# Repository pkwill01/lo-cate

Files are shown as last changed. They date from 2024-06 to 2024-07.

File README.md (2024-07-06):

# lo-cate
A PCB and firmware project to create a simple LoRa capable device with an intergrated IMU. 
## PCB
The PCB was designed to be simple, power over USB and be manufactorable using basic electrical tooling.

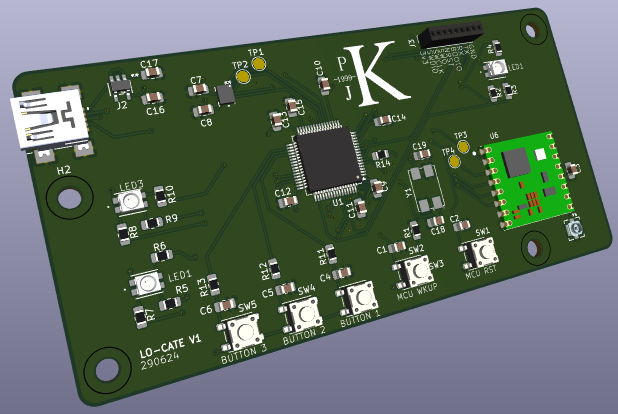
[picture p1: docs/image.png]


### Overview
 - **LoRa**; Connected to the micro via SPI, the antenna connection is terminated to a U.FL SMD connector w/ track impedance matched to 50&Omega;
 - **IMU**; Connected to micro via SPI 
 - **Microcontroller**; STM32F401RET7 w/ an 8MHz external oscillator to allow USB OTG capabilities. 
 - **USB**; Mini B for communicating between the STM and external PC, 5v in fed into a 3.3v linear reg for use by all IC's
 - **LED's**; 3 RGB LED's connected to the micros power outputs for baic HMI
 - **Buttons**; Debounced using RC filter and connected to interrupt capable pins on the micro, MCU WKUP is connected to the micros sleep wakeup pin

### PCB TODO 
 - [] Change the Programming header for the STM32 from the 1.27mm pins
 - [] Fix the oscillator circuit to fit into the STM32 design guidlines C19 & C18 should be calculated via C_L = 2*(C_Load - C_Stray) also R14 will need adjusting also 

## Firmware

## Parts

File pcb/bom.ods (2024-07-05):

Ord | Rec | Component | Spec | $ | Qty | Total $ | Ord | Rec | Reference | Value | Footprint | Qty | $ | Total $
y | y | LoRa Module (https://www.digikey.com.au/en/products/detail/rf-solutions/RFM95W-868S2/5051755?_gl=1*dk7re0*_up*MQ..) | RFM95W-868S2 | 22.68 | 1 | 22.68 | y | y | C1,C2,C3,C4,C5,C6,C7,C8,C9,C10,C11,C12,C13,C14,C16 | 0.1uF (https://www.digikey.com.au/en/products/detail/yageo/CC0805KRX7R9BB104/302874) | C_0805_2012 | 15 | 0.16 | 2.4
y | y | STM32 (https://www.digikey.com.au/en/products/detail/stmicroelectronics/STM32F401RET7/6621729?Enterprise=44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) | STM32F401RET7 | 8.59 | 1 | 8.59 | y | y | C15 | 4.7uF (https://www.digikey.com.au/en/products/detail/samsung-electro-mechanics/CL21A475KAQNNNE/3886902) | C_0805_2013 | 1 | 0.16 | 0.16
y | y | IMU (https://www.digikey.com.au/en/products/detail/bosch-sensortec/BMI323/16719593) | BMI323 | 7.1 | 1 | 7.1 | y | y | C17 | 0.47uF (https://www.digikey.com.au/en/products/detail/murata-electronics/GRM21BR71H474KA88L/702592) | C_0805_2014 | 1 | 0.36 | 0.36
y | y | Buttons (https://www.digikey.com.au/en/products/detail/c-k/PTS-647-SN50-SMTR2-LFS/9649857) | PTS 647 SN50 SMTR2 LFS | 0.28 | 5 | 1.4 | y | y | C18,C19 | 10p (https://www.digikey.com.au/en/products/detail/samsung-electro-mechanics/CL21C100CBANNNC/3888219) | C_0805_2015 | 2 | 0.16 | 0.32
y | y | Led’s (https://www.digikey.com.au/en/products/detail/würth-elektronik/150141M173100/4489960) | 150141M173100 | 0.57 | 2 | 1.14 | y | y | R1 | 10k (https://www.digikey.com.au/en/products/detail/yageo/RC0805FR-0710KL/727535) | R_0805_2012 | 1 | 0.16 | 0.16
y | y | USB Mini B (https://www.digikey.com.au/en/products/detail/edac-inc/690-005-299-043/4312191) | 690-005-299-043 | 1.02 | 1 | 1.02 | y | y | R2,R3,R4,R5,R6,R7,R8,R9,R10 | 60Ω (https://www.digikey.com.au/en/products/detail/yageo/RC0805FR-0760R4L/728073) | R_0805_2013 | 9 | 0.16 | 1.44
 |  | Programming Header | Header Pins | 3 | 1 | 3 | y | y | R11,R12,R13 | 50k (https://www.digikey.com.au/en/products/detail/vishay-beyschlag-draloric-bc-components/MCU08050D5002BP100/8125783) | R_0805_2014 | 3 | 1.33 | 3.99
y | y | Linear Regulator (https://www.digikey.com.au/en/products/detail/stmicroelectronics/LDK320AM33R/6192795) | LDK320AM33R | 1.04 | 1 | 1.04 | y | y | R14 | 30R (https://www.digikey.com.au/en/products/detail/yageo/RC0805FR-0730RL/727842) | R_0805_2015 | 1 | 0.28 | 0.28
y | y | Antenna (https://www.digikey.com.au/en/products/detail/molex/2067640100/9520958) | 2067640100 | 6.85 | 1 | 6.85
y | y | u.FL connector (https://www.digikey.com.au/en/products/detail/0734120114/WM3894CT-ND/2421931?curr=usd) | U.FL-R-SMT-1(10) | 1.51 | 1 | 1.51
y | y | Oscillator (https://www.digikey.com.au/en/products/detail/LFXTAL026380/1923-LFXTAL026380CT-ND/8634020?curr=usd) | LFXTAL026380 | 1.51 | 1 | 1.51 |  |  |  |  |  |  |  | 9.11
 |  |  |  | 1.3 | 1 | 1.3
 |  |  |  |  |  | 0
 |  |  |  |  |  | 0
 |  |  |  |  |  | 0
 |  |  |  |  |  | 52.82
 |  |  |  |  |  |  |  |  |  |  |  |  |  |  | 0.1uF

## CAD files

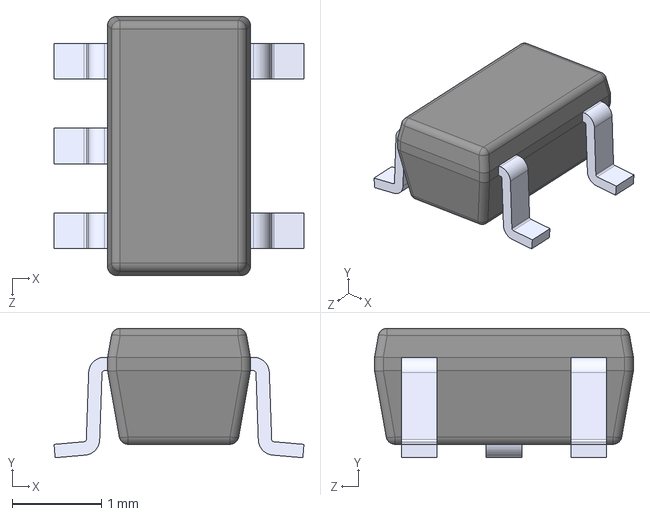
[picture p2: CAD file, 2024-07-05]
pcb/lo_cate_pcb/footprint_libs/step/LDK320AM33R.step
2.80 x 1.45 x 2.90 mm

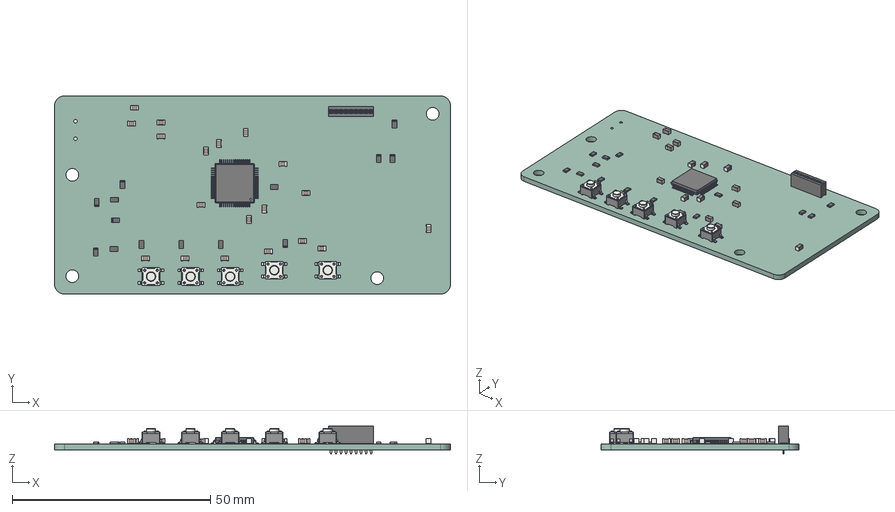
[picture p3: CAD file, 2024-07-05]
pcb/lo_cate_pcb/lo_cate_pcb.step
100.0 x 50.0 x 7.00 mm
SW_SPST_PTS647Sx38 x 5
C_0805_2012Metric x 19
R_0805_2012Metric x 14
PinSocket_1x09_P127mm_Vertical
LQFP_64_10x10mm_P05mm
lo_cate_pcb_PCB

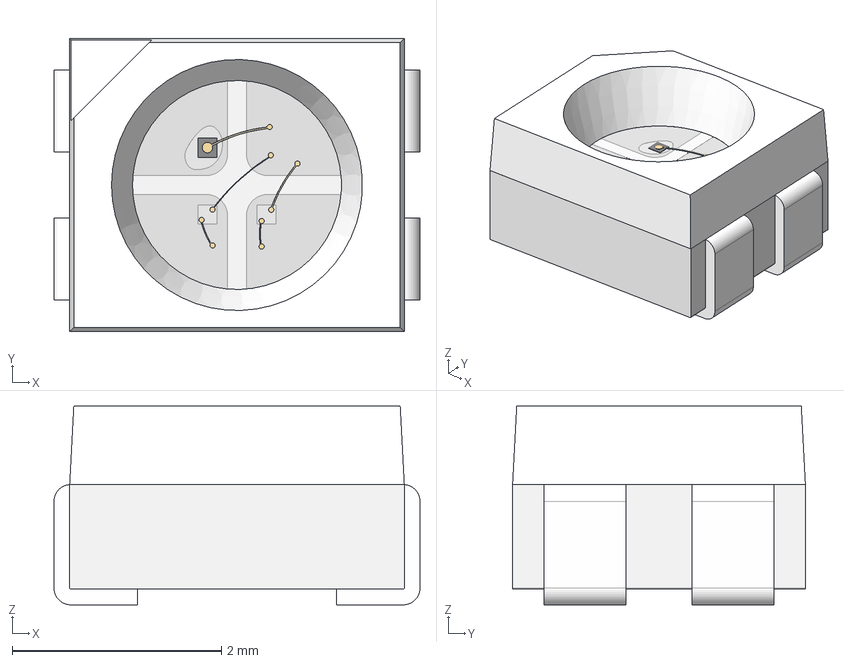
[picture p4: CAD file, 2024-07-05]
pcb/lo_cate_pcb/footprint_libs/step/WL-SFTW_3528_PLCC4.step
3.50 x 2.80 x 1.90 mm
cover
housing
base x 2

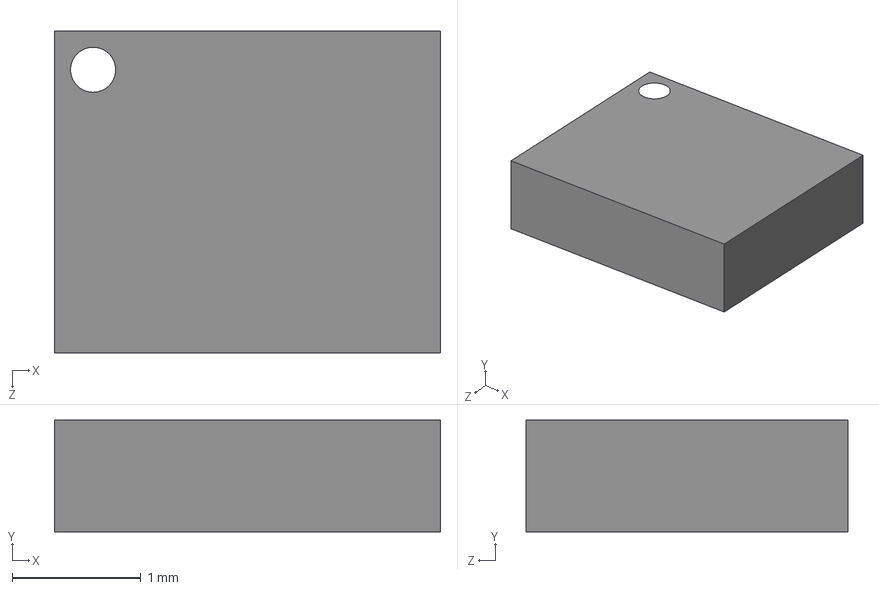
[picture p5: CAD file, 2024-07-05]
pcb/lo_cate_pcb/footprint_libs/step/BMI323.step
3.00 x 0.87 x 2.50 mm

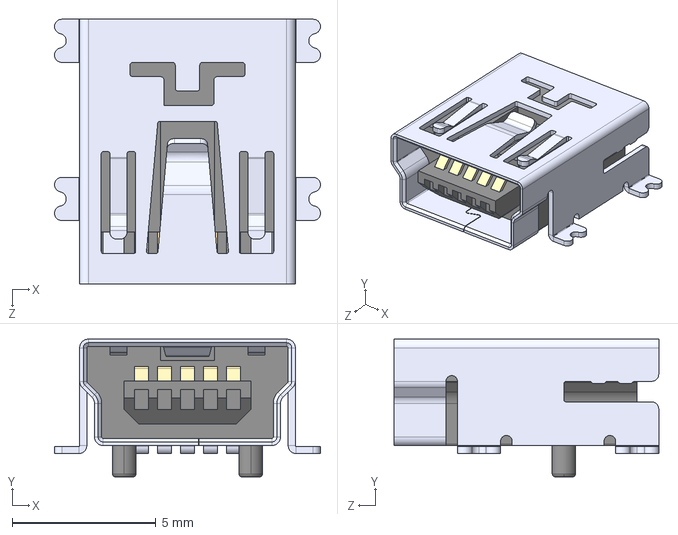
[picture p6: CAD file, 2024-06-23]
pcb/lo_cate_pcb/footprint_libs/step/690-005-299-043.step
9.25 x 4.79 x 9.20 mm

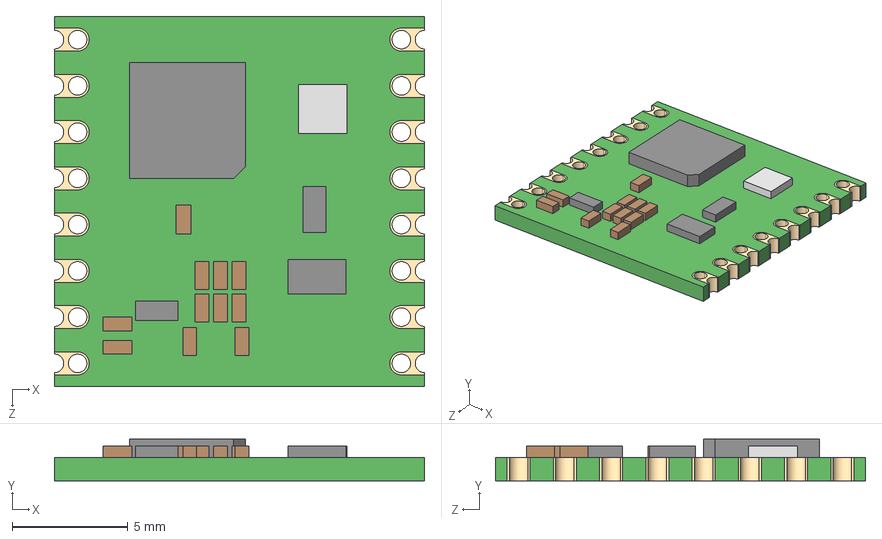
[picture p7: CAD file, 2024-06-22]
pcb/lo_cate_pcb/footprint_libs/step/RFM95W-868S2.step
16.0 x 1.80 x 16.0 mm

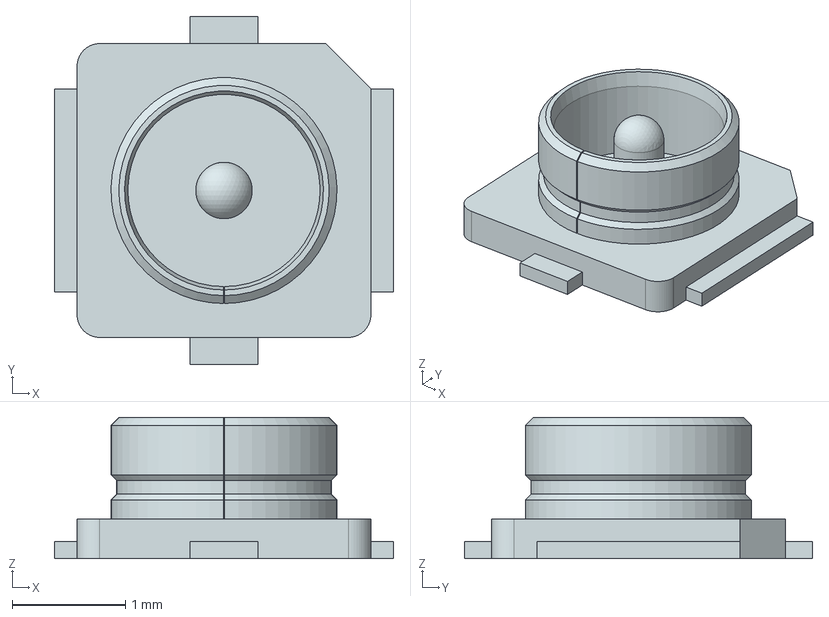
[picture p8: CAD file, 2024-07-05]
pcb/lo_cate_pcb/footprint_libs/step/734120114.stp
3.00 x 3.08 x 1.25 mm

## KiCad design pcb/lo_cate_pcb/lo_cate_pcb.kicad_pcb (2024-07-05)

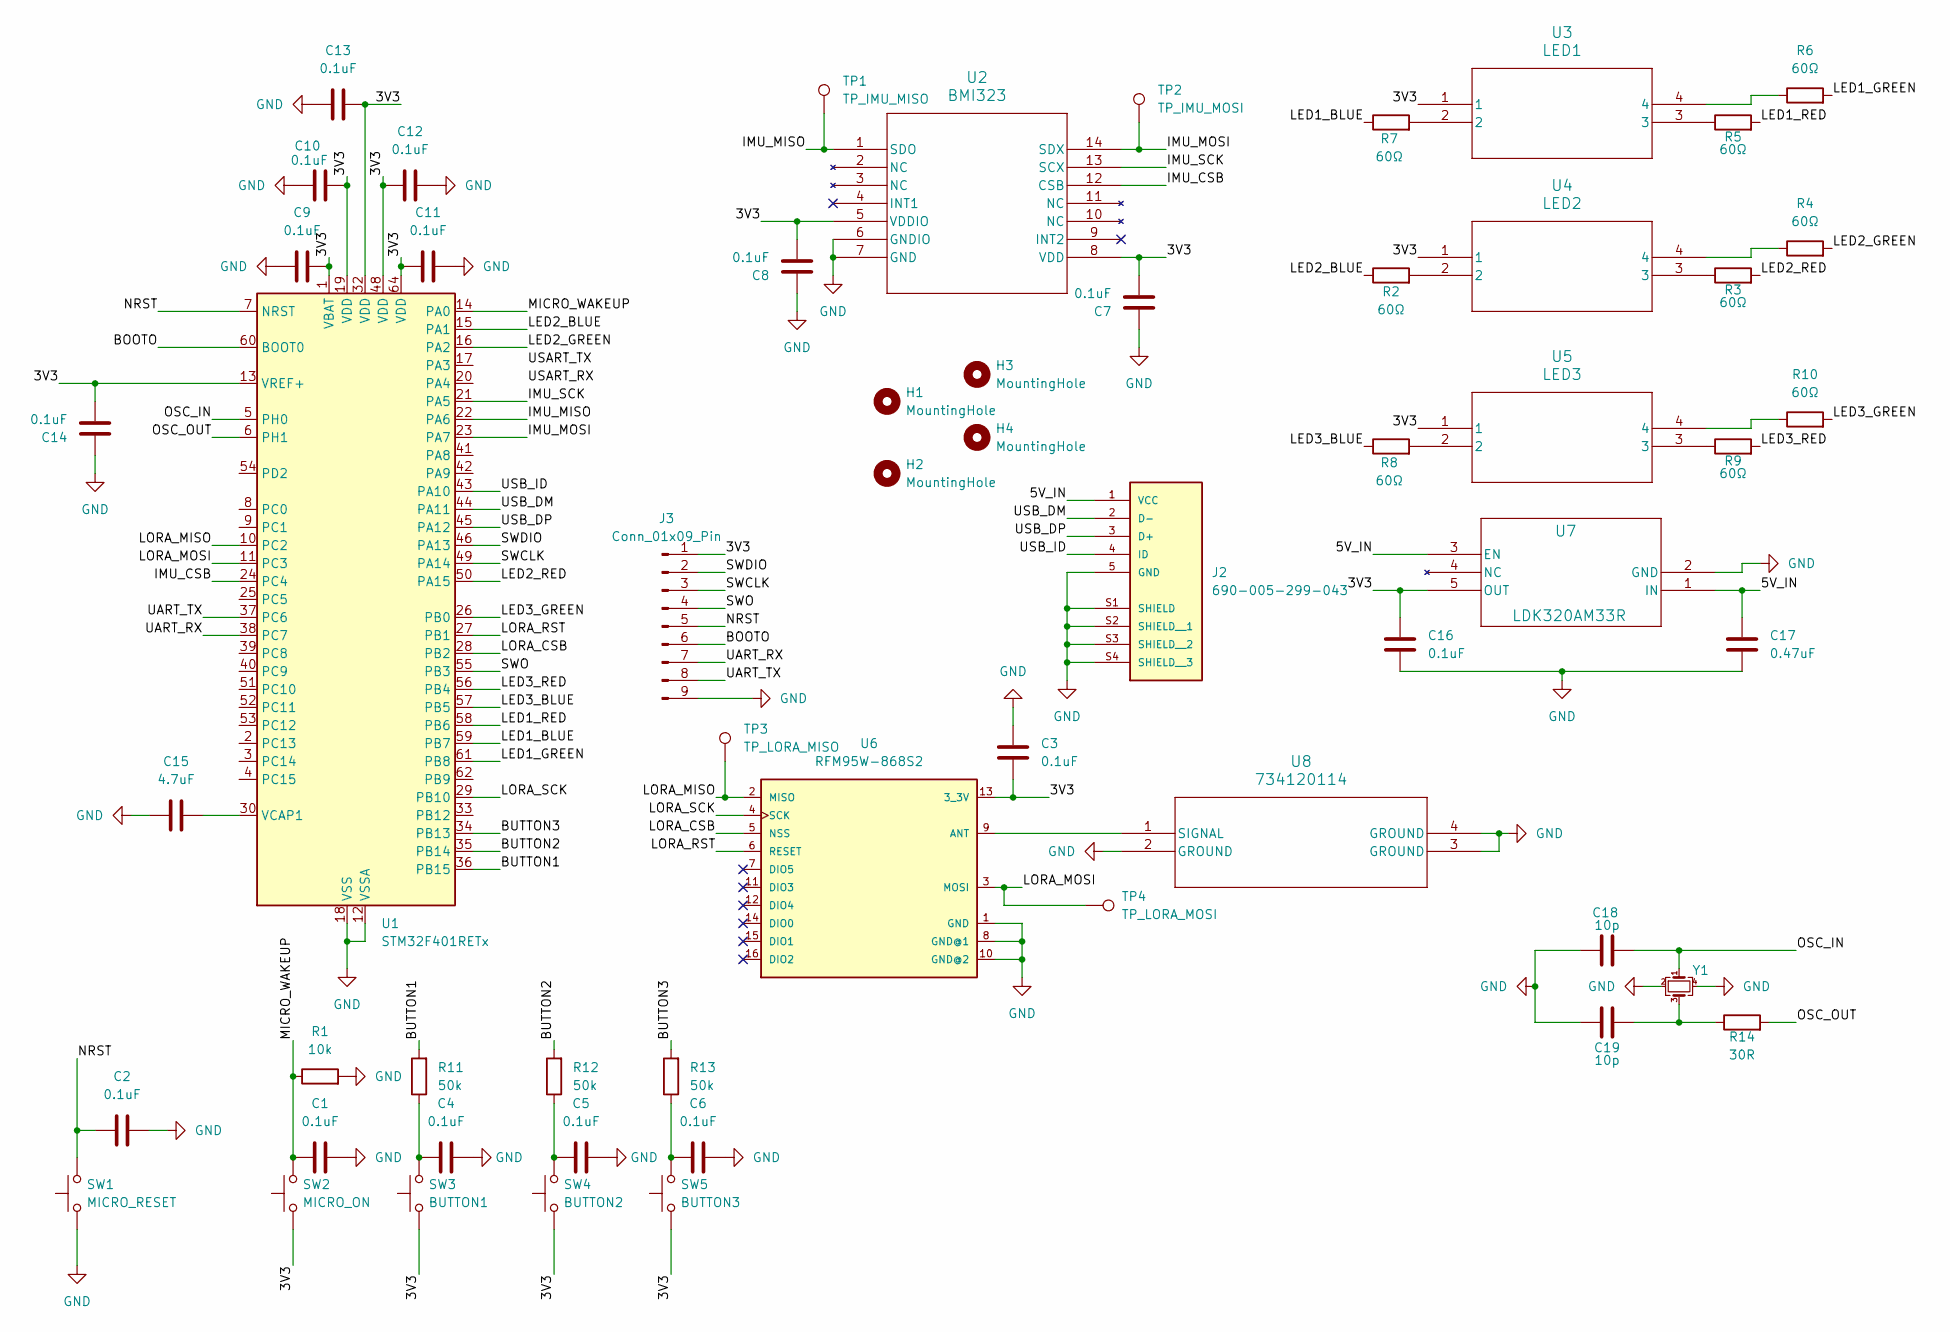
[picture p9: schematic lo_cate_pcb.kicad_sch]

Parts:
C1, C2, C3, C4, C5, C6, C7, C8, C9, C10, C11, C12, C13, C14, C16: 0.1uF; C_0805_2012Metric_Pad1.18x1.45mm_HandSolder
C15: 4.7uF; C_0805_2012Metric_Pad1.18x1.45mm_HandSolder
C17: 0.47uF; C_0805_2012Metric_Pad1.18x1.45mm_HandSolder
C18, C19: 10p; C_0805_2012Metric_Pad1.18x1.45mm_HandSolder
H1, H2, H3, H4: MountingHole; MountingHole_3.2mm_M3
J2: 690-005-299-043; EDAC_690-005-299-043; PARTREV 11
J3: Conn_01x09_Pin; PinSocket_1x09_P1.27mm_Vertical
R1: 10k; R_0805_2012Metric_Pad1.20x1.40mm_HandSolder
R2, R3, R4, R5, R6, R7, R8, R9, R10: 60Ω; R_0805_2012Metric_Pad1.20x1.40mm_HandSolder
R11, R12, R13: 50k; R_0805_2012Metric_Pad1.20x1.40mm_HandSolder
R14: 30R; R_0805_2012Metric_Pad1.20x1.40mm_HandSolder
SW1: MICRO_RESET; SW_SPST_PTS647_Sx38
SW2: MICRO_ON; SW_SPST_PTS647_Sx38
SW3: BUTTON1; SW_SPST_PTS647_Sx38
SW4: BUTTON2; SW_SPST_PTS647_Sx38
SW5: BUTTON3; SW_SPST_PTS647_Sx38
TP1: TP_IMU_MISO; TestPoint_Pad_D2.0mm
TP2: TP_IMU_MOSI; TestPoint_Pad_D2.0mm
TP3: TP_LORA_MISO; TestPoint_Pad_D2.0mm
TP4: TP_LORA_MOSI; TestPoint_Pad_D2.0mm
U1: STM32F401RETx; LQFP-64_10x10mm_P0.5mm
U2: BMI323; BMI323_BOS-M
U3: LED1; 150141M173100_WRE-M
U4: LED2; 150141M173100_WRE-M
U5: LED3; 150141M173100_WRE-M
U6: RFM95W-868S2; XCVR_RFM95W-868S2
U7: LDK320AM33R; SOT23-5L_STM-M
U8: 734120114; 73412-0114_MOL
Y1: Crystal_GND24_Small; Crystal_SMD_7050-4Pin_7.0x5.0mm

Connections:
/3V3: C3.2, C7.2, C8.2, C9.1, C10.1, C11.2, C12.2, C13.2, C14.2, C16.1, J3.1, SW2.1, SW3.1, SW4.1, SW5.1, U1.1 (VBAT), U1.13 (VREF+), U1.19 (VDD), U1.32 (VDD), U1.48 (VDD), U1.64 (VDD), U2.5 (VDDIO), U2.8 (VDD), U3.1, U4.1, U5.1, U6.13 (3_3V), U7.5 (OUT)
/5V_IN: C17.1, J2.1 (VCC), U7.1 (IN), U7.3 (EN)
/BOOTO: J3.6, U1.60 (BOOT0)
/BUTTON1: R11.2, U1.36 (PB15)
/BUTTON2: R12.2, U1.35 (PB14)
/BUTTON3: R13.2, U1.34 (PB13)
/IMU_CSB: U1.24 (PC4), U2.12 (CSB)
/IMU_MISO: TP1.1, U1.22 (PA6), U2.1 (SDO)
/IMU_MOSI: TP2.1, U1.23 (PA7), U2.14 (SDX)
/IMU_SCK: U1.21 (PA5), U2.13 (SCX)
/LED1_BLUE: R7.1, U1.59 (PB7)
/LED1_GREEN: R6.2, U1.61 (PB8)
/LED1_RED: R5.2, U1.58 (PB6)
/LED2_BLUE: R2.1, U1.15 (PA1)
/LED2_GREEN: R4.2, U1.16 (PA2)
/LED2_RED: R3.2, U1.50 (PA15)
/LED3_BLUE: R8.1, U1.57 (PB5)
/LED3_GREEN: R10.2, U1.26 (PB0)
/LED3_RED: R9.2, U1.56 (PB4)
/LORA_CSB: U1.28 (PB2), U6.5 (NSS)
/LORA_MISO: TP3.1, U1.10 (PC2), U6.2 (MISO)
/LORA_MOSI: TP4.1, U1.11 (PC3), U6.3 (MOSI)
/LORA_RST: U1.27 (PB1), U6.6 (RESET)
/LORA_SCK: U1.29 (PB10), U6.4 (SCK)
/MICRO_WAKEUP: C1.2, R1.1, SW2.2, U1.14 (PA0)
/NRST: C2.2, J3.5, SW1.2, U1.7 (NRST)
/OSC_IN: C18.1, U1.5 (PH0), Y1.1
/OSC_OUT: R14.2, U1.6 (PH1)
/SWCLK: J3.3, U1.49 (PA14)
/SWDIO: J3.2, U1.46 (PA13)
/SWO: J3.4, U1.55 (PB3)
/UART_RX: J3.7, U1.38 (PC7)
/UART_TX: J3.8, U1.37 (PC6)
/USB_DM: J2.2 (D-), U1.44 (PA11)
/USB_DP: J2.3 (D+), U1.45 (PA12)
/USB_ID: J2.4 (ID), U1.43 (PA10)
GND: C1.1, C2.1, C3.1, C4.1, C5.1, C6.1, C7.1, C8.1, C9.2, C10.2, C11.1, C12.1, C13.1, C14.1, C15.2, C16.2, C17.2, C18.2, C19.2, J2.5 (GND), J2.S1 (SHIELD), J2.S2 (SHIELD__1), J2.S3 (SHIELD__2), J2.S4 (SHIELD__3), J3.9, R1.2, SW1.1, U1.12 (VSSA), U1.18 (VSS), U1.31 (VSS), U1.47 (VSS), U1.63 (VSS), U2.6 (GNDIO), U2.7 (GND), U6.1 (GND), U6.8 (GND@1), U6.10 (GND@2), U7.2 (GND), U8.2 (GROUND), U8.3 (GROUND), U8.4 (GROUND), Y1.2, Y1.4
unnamed: C4.2, R11.1, SW3.2
unnamed: C5.2, R12.1, SW4.2
unnamed: C6.2, R13.1, SW5.2
unnamed: C19.1, R14.1, Y1.3
unnamed: R2.2, U4.2
unnamed: R3.1, U4.3
unnamed: R4.1, U4.4
unnamed: R5.1, U3.3
unnamed: R6.1, U3.4
unnamed: R7.2, U3.2
unnamed: R8.2, U5.2
unnamed: R9.1, U5.3
unnamed: R10.1, U5.4
unnamed: C15.1, U1.30 (VCAP1)
unnamed: U6.9 (ANT), U8.1 (SIGNAL)

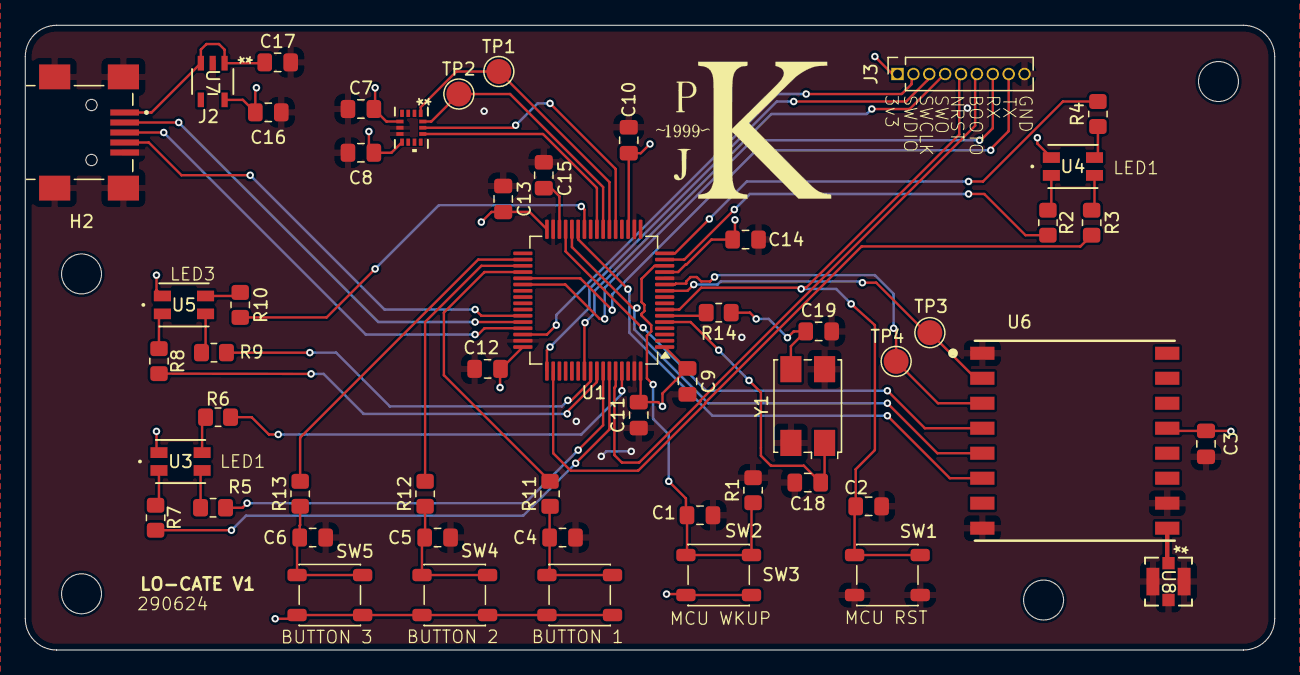
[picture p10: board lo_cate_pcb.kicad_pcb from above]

Board: 4 copper layers, 100.0 x 50.0 mm, 57 parts (0 on the bottom side), 52 nets.

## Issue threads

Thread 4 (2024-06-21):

PCB, Design Antenna For the LoRa Module

pkwill01, 2024-06-21:

pkwill01, 2024-06-24:
- [] Work out how to connect SMA connector
- [] Find a Suitable antenna assembly
- [] Work out method of antenna mounting

Closed 2024-06-29.

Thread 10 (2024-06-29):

Testing PCB

pkwill01, 2024-06-29:

pkwill01, 2024-06-29:
- [] Test the 3.3V to 5V regulator output
 - [] Oscilloscope the Crystal Resonator and check for 8MHz
 - [] Check STM32 can be detected using CubeMX
 - [] Check the Input Voltage for the LoRa Module is 3.3V
 - [] Hello World from USB connection
 - [] Hello World Led flash

pkwill01, 2024-07-23:
## Testing PCB V2
 - [ ]  - [ ] Test the 3.3V to 5V regulator output
 - [x] Oscilloscope the Crystal Resonator and check for 8MHz
 - [x] Check STM32 can be detected using CubeMX
 - [x] Check the Input Voltage for the LoRa Module is 3.3V
 - [x] Hello World from USB connection
 - [x] Hello World Led flash
 - [ ] Communicate with the IMU
 - [x] Communicate with the LORA module
 - [ ] Test LoRa Send
 - [ ] Test LoRa Receive

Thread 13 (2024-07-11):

Compile a list of PCB changes

pkwill01, 2024-07-11:

pkwill01, 2024-07-11:
Current Issues
  - [] The programming header does not fit the desired pins, needs to be changed to an actual connector or just the 2.57mm  pitch pins
  - [] Crystal oscillator does not need REXT and the capacitors are slightly wrong in values 10pF -> 12pF
  - [] RGB LED footprints are incorrect, need to be edited to align with data sheet
  - [] Find a LORA footprint with wider solder feet for easier hand soldering

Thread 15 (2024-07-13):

Unable to communicate with the LORA module on PCB v1

pkwill01, 2024-07-13:
So far I have not been able to communicate with the LORA module on SPI2, attaching a logic analyser while trying to read from the ID resister gives this result
``` C
HAL_GPIO_WritePin(LORA_CSB_GPIO_Port, LORA_CSB_Pin, GPIO_PIN_RESET);
hal_status = HAL_SPI_TransmitReceive(&hspi2, tx_data, rx_data, 2, 1000);
HAL_GPIO_WritePin(LORA_CSB_GPIO_Port, LORA_CSB_Pin, GPIO_PIN_SET);
HAL_Delay(500);
```
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
In image you can see:
 - No clock pulses
 - MOSI is transmitting
 - RST pin is in the correct position
 - Enable pin is in correct position

 From the RFM data sheet the process of reading a register should look like this
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

pkwill01, 2024-07-13:
# CPOL and CPHA
The stm32 is configured correctly as
 - CPOL = 0
 - CPHA = 0

Changing CPOL to high to see if pin voltage goes to nominally high yields:
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
 i.e the pin is still nominally low rather then high

pkwill01, 2024-07-13:
## Solution
The SPI2 for the stm32F4 has 2 SCK output options, the default when configuring is PB13 which in this case meant that the LORA module was receiving no clock. Rectifying this now shows the peripheral hello world working:
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
MOSI sending the read register message for `RegVersion i.e  0x42` and the RMF responding with `0x12`

pkwill01, 2024-07-13:
## Solution
The SPI2 for the stm32F4 has 2 SCK output options, the default when configuring is PB13 which in this case meant that the LORA module was receiving no clock. Rectifying this now shows the peripheral hello world working:
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
MOSI sending the read register message for `RegVersion i.e  0x42` and the RMF responding with `0x12`

Closed 2024-07-13.

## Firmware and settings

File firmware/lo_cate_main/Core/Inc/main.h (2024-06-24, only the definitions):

#define LORA_MISO_Pin GPIO_PIN_2
#define LORA_MISO_GPIO_Port GPIOC
#define LORA_MOSI_Pin GPIO_PIN_3
#define LORA_MOSI_GPIO_Port GPIOC
#define LED2_BLUE_Pin GPIO_PIN_1
#define LED2_BLUE_GPIO_Port GPIOA
#define IMU_SCK_Pin GPIO_PIN_5
#define IMU_SCK_GPIO_Port GPIOA
#define IMU_MISO_Pin GPIO_PIN_6
#define IMU_MISO_GPIO_Port GPIOA
#define IMU_MOSI_Pin GPIO_PIN_7
#define IMU_MOSI_GPIO_Port GPIOA
#define IMU_CSB_Pin GPIO_PIN_4
#define IMU_CSB_GPIO_Port GPIOC
#define LED3_GREEN_Pin GPIO_PIN_0
#define LED3_GREEN_GPIO_Port GPIOB
#define LORA_SCK_Pin GPIO_PIN_13
#define LORA_SCK_GPIO_Port GPIOB
#define LED3_RED_Pin GPIO_PIN_6
#define LED3_RED_GPIO_Port GPIOC
#define LED3_BLUE_Pin GPIO_PIN_7
#define LED3_BLUE_GPIO_Port GPIOC
#define USB_ID_Pin GPIO_PIN_10
#define USB_ID_GPIO_Port GPIOA
#define USB_DM_Pin GPIO_PIN_11
#define USB_DM_GPIO_Port GPIOA
#define USB_DP_Pin GPIO_PIN_12
#define USB_DP_GPIO_Port GPIOA
#define LED2_RED_Pin GPIO_PIN_15
#define LED2_RED_GPIO_Port GPIOA
#define LED1_RED_Pin GPIO_PIN_6
#define LED1_RED_GPIO_Port GPIOB
#define LED1_BLUE_Pin GPIO_PIN_7
#define LED1_BLUE_GPIO_Port GPIOB
#define LED1_GREEN_Pin GPIO_PIN_8
#define LED1_GREEN_GPIO_Port GPIOB

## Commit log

2024-06-20 Basic PCB Design
    [bom.ods, lo_cate_pcb.kicad_pcb, lo_cate_pcb.kicad_sch]
2024-06-21 Found footprint and sch files for most components
2024-06-21 Added footprint files for most componenets
    [bom.ods, lo_cate_pcb.kicad_sch]
2024-06-22 Added basic firmware folder
    [RFM95W-868S2.step, bom.ods]
2024-06-22 Finished basic PCB connections, now need to do the power electronics and antenna
    [bom.ods, lo_cate_pcb.kicad_sch]
2024-06-23 USB connector added to pcb, All that is left is power electronics and antenna
    [690-005-299-043.step]
2024-06-23 Started the PCB Layout
    [bom.ods, lo_cate_pcb.kicad_pcb, lo_cate_pcb.kicad_sch]
2024-06-24 Added smt connector
    [bom.ods, lo_cate_pcb.kicad_pcb, lo_cate_pcb.kicad_sch]
2024-06-26 Most PCB Routing is complete
    [lo_cate_pcb.kicad_pcb]
2024-06-27 Final PCB design done
    [bom.ods, lo_cate_pcb.kicad_pcb, lo_cate_pcb.kicad_sch]
2024-06-29 Changed PCB to a 4 Layer Version
    [lo_cate_pcb.kicad_pcb, lo_cate_pcb.kicad_sch]
2024-06-29 Added an external crystal oscillator
    [bom.ods, lo_cate_pcb.kicad_pcb, lo_cate_pcb.kicad_sch]
2024-06-29 Finished PCB?
    [lo_cate_pcb.kicad_pcb]
2024-06-29 Moved the Oscillator slightly to help with assembly
    [lo_cate_pcb.kicad_pcb]
2024-06-29 Altered the Oscillator Path
    [lo_cate_pcb.kicad_pcb]
2024-06-29 broke a usart to header pins
    [bom.ods, lo_cate_pcb.kicad_pcb, lo_cate_pcb.kicad_sch]
2024-06-29 Submitted PCB for manufactoring
    [bom.ods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]
2024-07-05 Added the step files for all the componenets on the PCB
    [690-005-299-043.step, 734120114.stp, BMI323.step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]
2024-07-05 Updated readme to reflect finished PCB design
2024-07-06 Added some additional PCB to do's

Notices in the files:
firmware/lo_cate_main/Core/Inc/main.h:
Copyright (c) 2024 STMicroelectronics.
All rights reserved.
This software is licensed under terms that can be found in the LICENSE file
